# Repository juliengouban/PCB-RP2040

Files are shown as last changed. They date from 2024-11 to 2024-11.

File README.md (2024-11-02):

# PCB-RP2040

We've realized an electronic board based on the RP2040.
This microcontroller has 2 MB of flash memory, providing ample storage space for programs and data. It has 26 digital I/O pins, 3 of which can be used as analog inputs.
The RP20240 is used for the Raspberry Pico board and is programmable in micro-Python or directly with Arduino Ide.
We developed the board on Kicad and had it manufactured on jpclb. It costs around 17 euros per board, and is a 2-layer board measuring 2.7cm x 2 cm. You can find the files on our github.

<h1> Electronic diagram</h1>
We'll now take a closer look at how our electronic board works: 

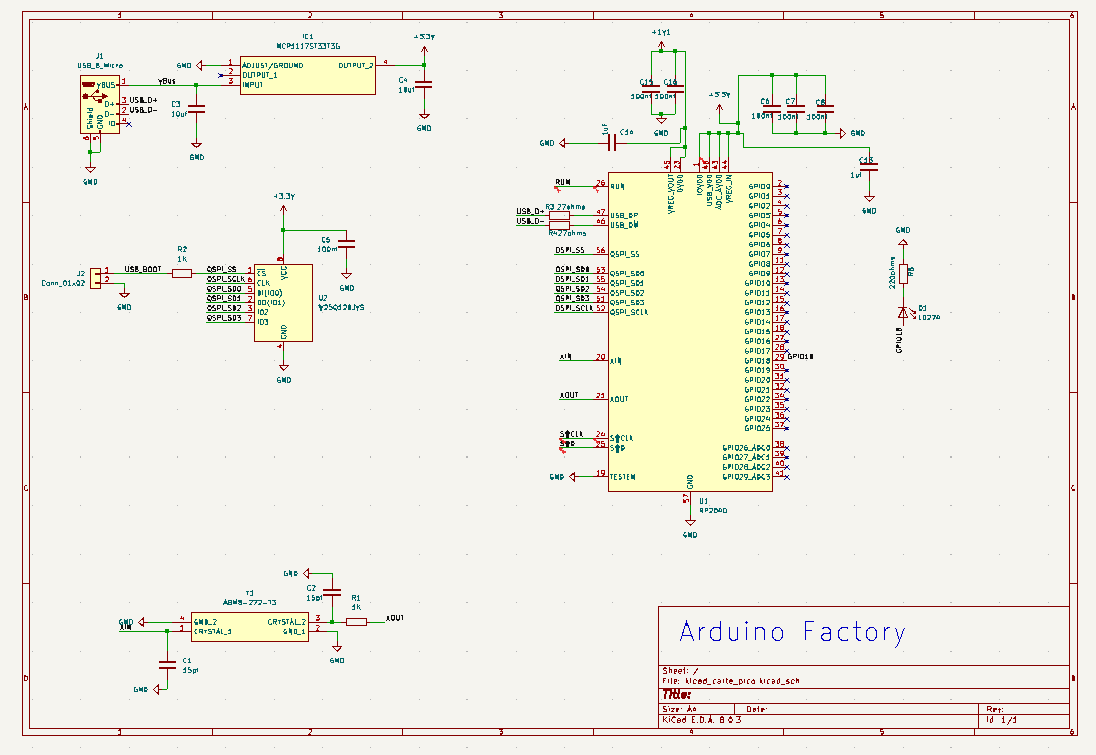
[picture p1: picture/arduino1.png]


For powering the circuit, we've used a Micro USB type B connector to supply our board with 5V. As the RP2040 uses 3.3V, we've fitted a regulator to convert 5V to +3.3V: 

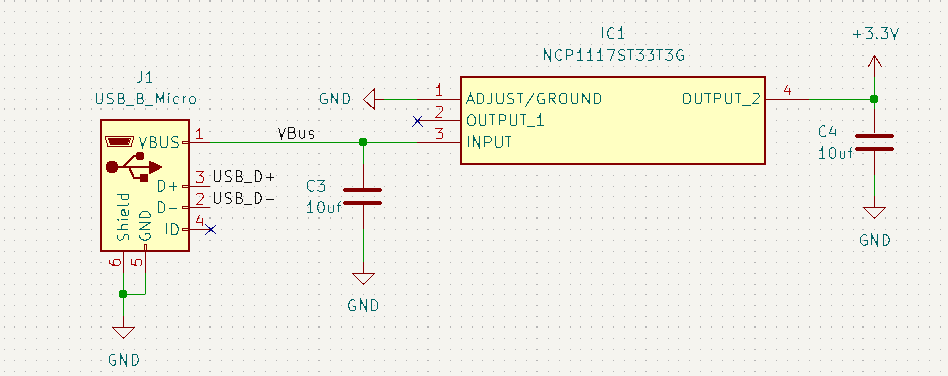
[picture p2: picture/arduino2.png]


This is where you'll find the 128-megabit flash memory to store the program. The 2-pin connector allows you to force USB boot:

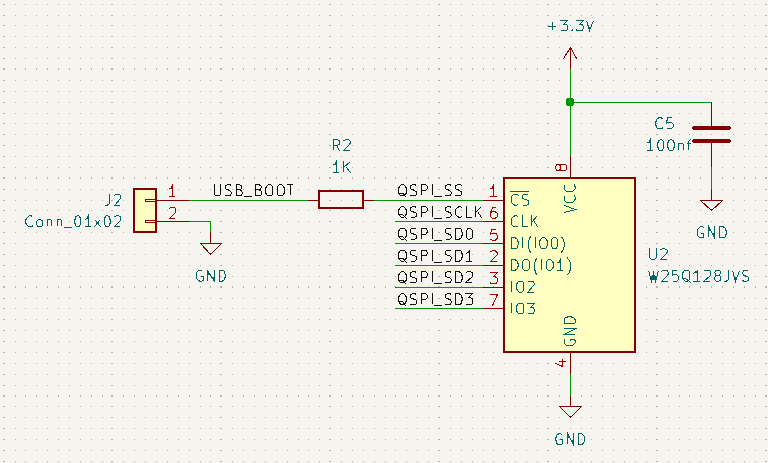
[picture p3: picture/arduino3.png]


The 12Mhz crystal provides the clock for our RP2040 microcontroller:

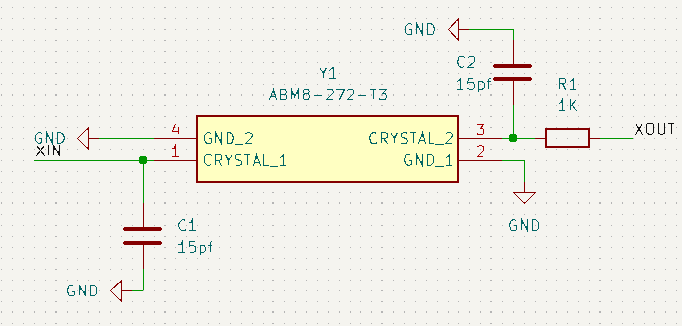
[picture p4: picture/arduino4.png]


We have added a LED to be programmed on GPIO18 to check that our card is working properly: 
PCB in 3D view

Finally, we have the RP2040 microncontroller. It is supplied with 3.3V with decoupling capacitors:
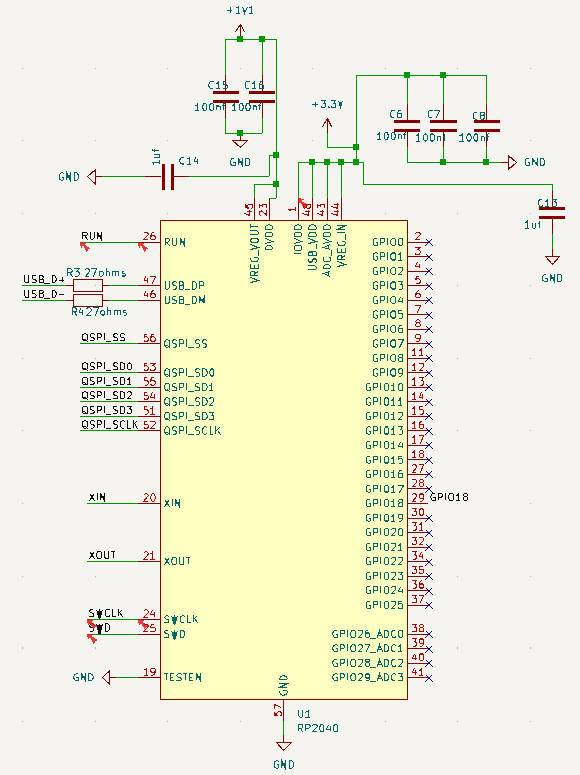
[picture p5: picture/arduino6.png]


<h1>PCB Design</h1>

The board is a 2-layer design. On the top you can see the 3.3V regulator and the Micro-USB type B connector.
In the middle of the board you'll find the flash memory and the RP2040 microcontroller.
At the bottom of the board you'll find the 2-pin USB boot connector and the 12Mhz quartz crystal.
A ground plane has been created on the TOP layer to connect all the GNDs together.

Here are the 3d and top layer views of the PCB:

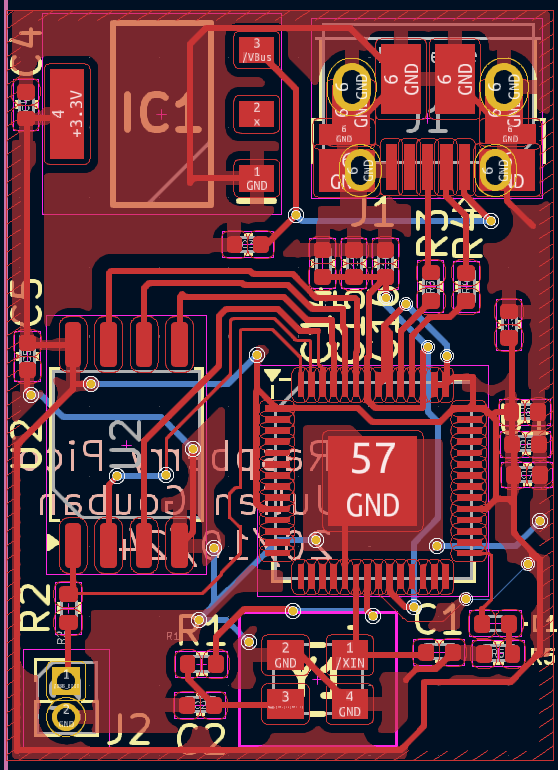
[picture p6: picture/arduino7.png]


Here is a 3d view of the PCB:

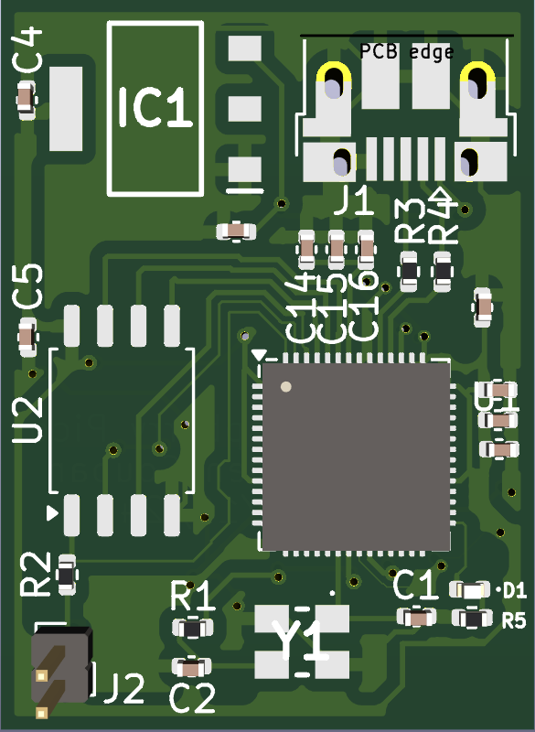
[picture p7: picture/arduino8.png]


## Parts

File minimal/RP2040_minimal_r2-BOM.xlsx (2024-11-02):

RP2040_minimal_r2 BOM
Item | Quantity | Reference | Part | Voltage | Current | Power | Material | Size | Tolerance | Manufacturer | Manuf. Part # | Description | Notes
1 | 3 | C1,C4,C17 | 10u | 16V |  |  | X5R | 0805_2012Metric | 10% | Murata | GRM21BR61C106KE15K | CAP CER 10UF 16V X5R 0805 | Or equivalent
2 | 2 | C2, C3 | 15p | 50V |  |  | C0G | 0402_1005Metric | 5% | Murata | GCM1555C1H150JA16D | CAP CER 15PF 50V C0G/NP0 0402 | Or equivalent
3 | 10 | C5, C6, C7, C9, C11, C12, C13, C14, C15, C16 | 100n | 25V |  |  | X7R | 0402_1005Metric | 10% | Murata | GRM155R71E104KE14J | CAP CER 0.1UF 25V X7R 0402 | Or equivalent
4 | 2 | C8, C10 | 1u | 10V |  |  | X6S | 0402_1005Metric | 10% | Murata | GRM155C81A105KA12D | CAP CER 1UF 10V X6S 0402 | Or equivalent
5 | 1 | J1 | USB_B_Micro |  |  |  |  |  |  | Amphenol | 10103594-0001LF | CONN RCPT USB2.0 MICRO B SMD R/A | Or equivalent
6 | 1 | J2 | 1x2 way header |  |  |  |  |  |  | Samtec | TSW-102-23-T-S | 2.54mm pin header 1x2 | Or equivalent
7 | 2 | J3, J4 | 2x18 way header |  |  |  |  |  |  | Samtec | TSW-118-23-T-D | 2.54mm pin header 2x18 | Or equivalent
8 | 2 | R1, R5 | 1k |  |  | 63mW |  | 0402_1005Metric | 1% | Yageo | RC0402FR-071KP | RES SMD 1K OHM 1% 1/16W 0402 | Or equivalent
9 | 1 | R2 | DNF |  |  |  |  | 0402_1005Metric |  |  |  |  | Do Not Fit
10 | 2 | R3, R4 | 27.4 |  |  | 63mW |  | 0402_1005Metric | 1% | Yageo | RC0402FR-0727R4L | RES SMD 27.4 OHM 1% 1/16W 0402 | Or equivalent
11 | 1 | U1 | NCP1117-3.3 |  |  |  |  | SOT-223-3 |  | ON Semiconductor | NCP1117ST33T3G | IC REG LINEAR 3.3V 1A SOT223
12 | 1 | U2 | W25Q128JVS |  |  |  |  | SOIC-8 |  | Winbond | W25Q128JVSIQ TR | IC FLASH 128M SPI 133MHZ 8SOIC
13 | 1 | U3 | RP2040 |  |  |  |  | QFN56 |  | Raspberry Pi | RP2040
14 | 1 | Y1 | ABM8-272-T3 |  |  |  |  | SMD_3225 |  | Abracon | ABM8-272-T3 | CRYSTAL 12.0000MHZ 3.2x2.5MM SMD

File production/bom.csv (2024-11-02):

Designator | Footprint | Quantity | Value | LCSC Part #
C1, C2 | 0402 | 2 | 15pf
C13, C14 | 0402 | 2 | 1uf
C15, C16, C5, C6, C7, C8 | 0402 | 6 | 100nf
C3, C4 | 0402 | 2 | 10uf
D1 | 0402 | 1 | LD274
IC1 | SOT230P700X180-4N | 1 | NCP1117ST33T3G
J1 | USB_Micro-B_Amphenol_10103594-0001LF_Horizontal | 1 | USB_B_Micro
J2 | PinHeader_1x02_P1.27mm_Vertical | 1 | Conn_01x02
R1, R2 | 0402 | 2 | 1K
R3, R4 | 0402 | 2 | 27ohms
R5 | 0402 | 1 | 220ohms
U1 | QFN-56-1EP_7x7mm_P0.4mm_EP3.2x3.2mm | 1 | RP2040
U2 | SOIC-8_5.23x5.23mm_P1.27mm | 1 | W25Q128JVS
Y1 | ABM8272T3 | 1 | ABM8-272-T3

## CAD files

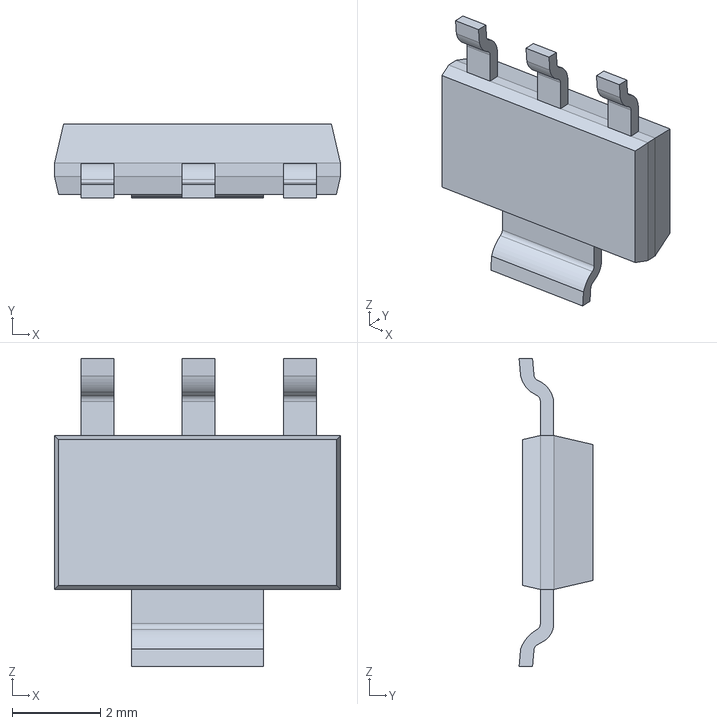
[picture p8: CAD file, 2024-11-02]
NCP1117/ncp1117st50t3g.stp
6.50 x 1.68 x 7.00 mm

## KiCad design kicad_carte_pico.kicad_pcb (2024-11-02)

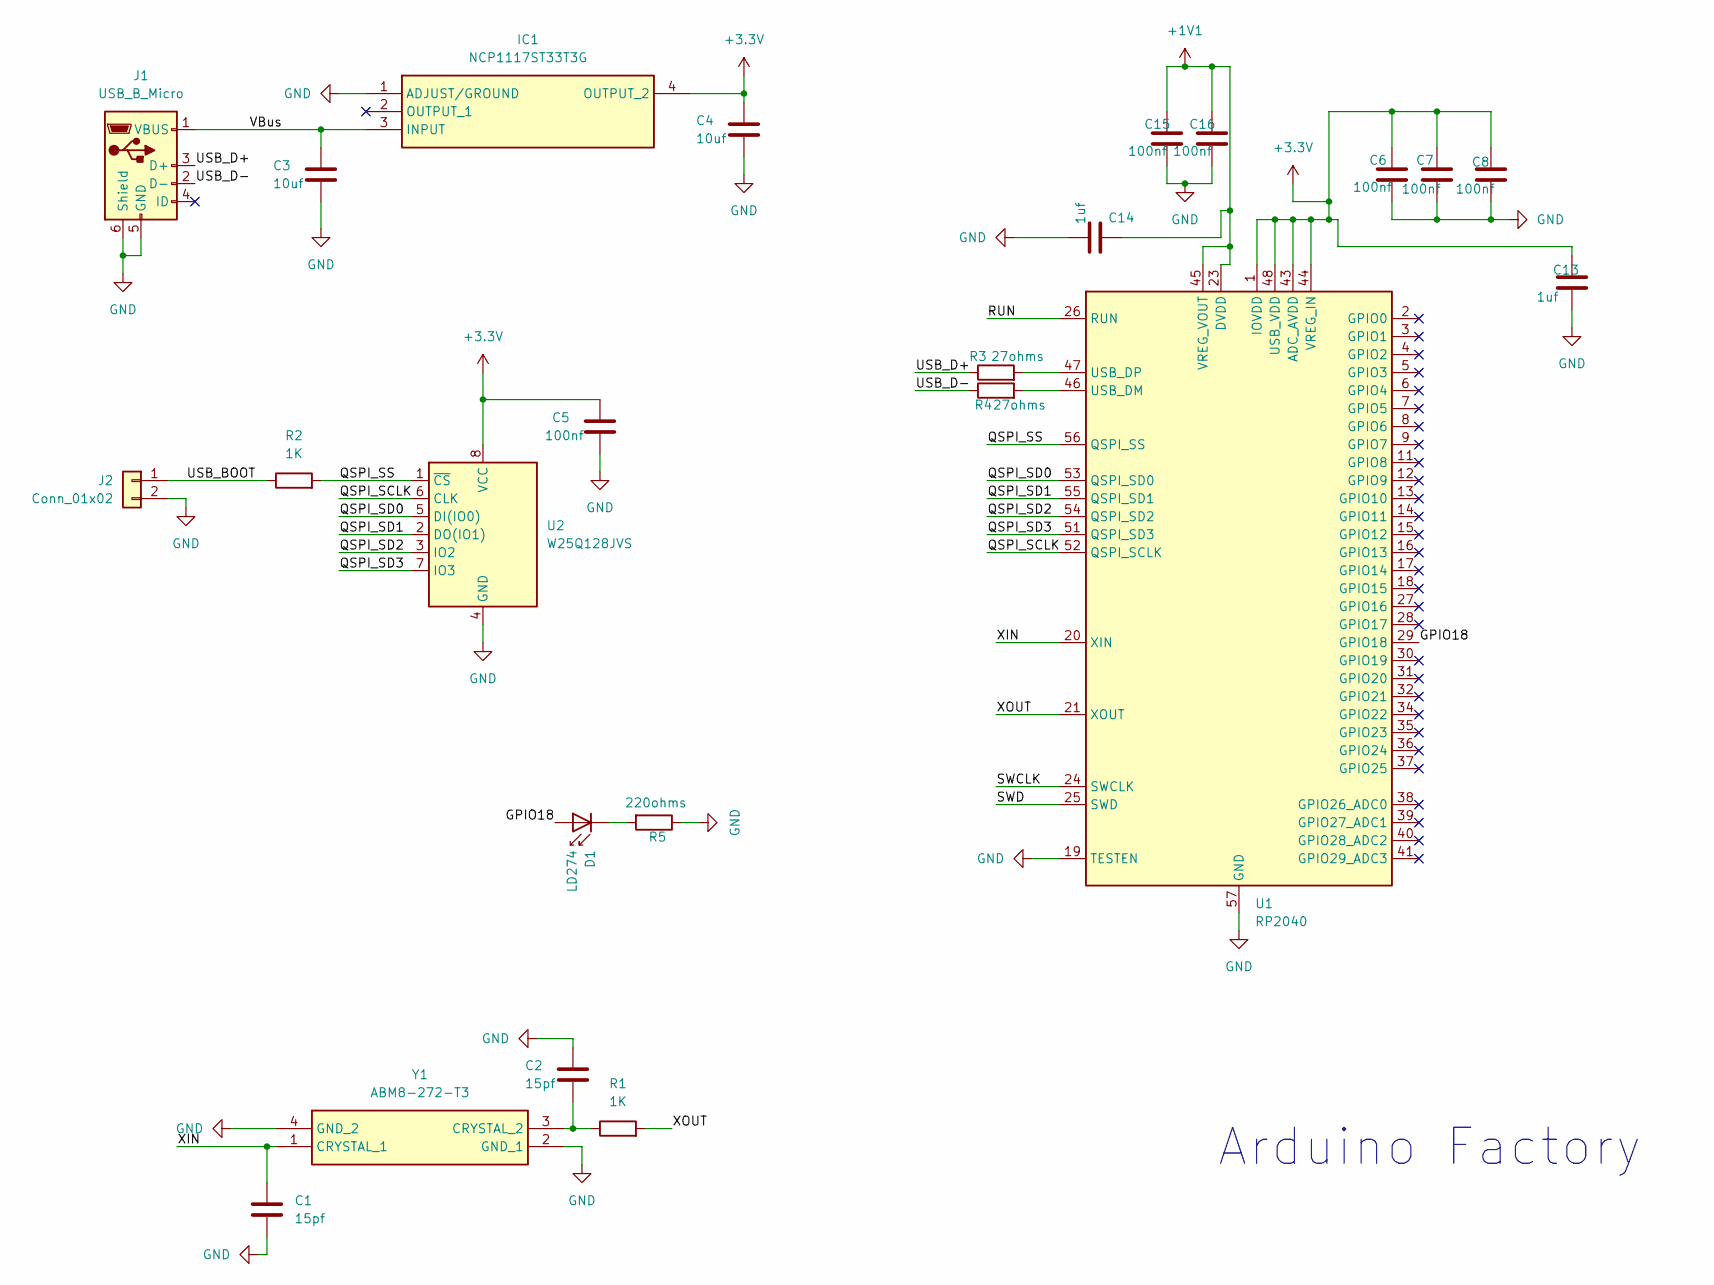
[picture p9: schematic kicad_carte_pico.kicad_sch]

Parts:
C1, C2: 15pf; C_0402_1005Metric
C3, C4: 10uf; C_0402_1005Metric
C5, C6, C7, C8, C15, C16: 100nf; C_0402_1005Metric
C13, C14: 1uf; C_0402_1005Metric
D1: LD274; LED_0402_1005Metric
IC1: NCP1117ST33T3G; SOT230P700X180-4N; Manufacturer_Part_Number NCP1117ST33T3G; Mouser Part Number 863-NCP1117ST33T3G
J1: USB_B_Micro; USB_Micro-B_Amphenol_10103594-0001LF_Horizontal
J2: Conn_01x02; PinHeader_1x02_P1.27mm_Vertical
R1, R2: 1K; R_0402_1005Metric
R3, R4: 27ohms; R_0402_1005Metric
R5: 220ohms; R_0402_1005Metric
U1: RP2040; QFN-56-1EP_7x7mm_P0.4mm_EP3.2x3.2mm
U2: W25Q128JVS; SOIC-8_5.23x5.23mm_P1.27mm
Y1: ABM8-272-T3; ABM8272T3; Mouser Part Number 815-ABM8-272-T3

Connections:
+1V1: C14.1, C15.1, C16.1, U1.23 (DVDD), U1.45 (VREG_VOUT), U1.50 (DVDD)
+3.3V: C4.1, C5.1, C6.1, C7.1, C8.1, C13.1, IC1.4 (OUTPUT_2), U1.1 (IOVDD), U1.10 (IOVDD), U1.22 (IOVDD), U1.33 (IOVDD), U1.42 (IOVDD), U1.43 (ADC_AVDD), U1.44 (VREG_IN), U1.48 (USB_VDD), U1.49 (IOVDD), U2.8 (VCC)
/GPIO18: D1.2 (A), U1.29 (GPIO18)
/QSPI_SCLK: U1.52 (QSPI_SCLK), U2.6 (CLK)
/QSPI_SD0: U1.53 (QSPI_SD0), U2.5 (DI(IO0))
/QSPI_SD1: U1.55 (QSPI_SD1), U2.2 (DO(IO1))
/QSPI_SD2: U1.54 (QSPI_SD2), U2.3 (IO2)
/QSPI_SD3: U1.51 (QSPI_SD3), U2.7 (IO3)
/QSPI_SS: R2.2, U1.56 (QSPI_SS), U2.1 (~CS)
/RUN: U1.26 (RUN)
/SWCLK: U1.24 (SWCLK)
/SWD: U1.25 (SWD)
/USB_BOOT: J2.1, R2.1
/USB_D+: J1.3 (D+), R3.1
/USB_D-: J1.2 (D-), R4.1
/VBus: C3.1, IC1.3 (INPUT), J1.1 (VBUS)
/XIN: C1.1, U1.20 (XIN), Y1.1 (CRYSTAL_1)
/XOUT: R1.2, U1.21 (XOUT)
GND: C1.2, C2.1, C3.2, C4.2, C5.2, C6.2, C7.2, C8.2, C13.2, C14.2, C15.2, C16.2, IC1.1 (ADJUST/GROUND), J1.5 (GND), J1.6 (Shield), J2.2, R5.1, U1.19 (TESTEN), U1.57 (GND), U2.4 (GND), Y1.2 (GND_1), Y1.4 (GND_2)
unnamed: D1.1 (K), R5.2
unnamed: R4.2, U1.46 (USB_DM)
unnamed: R3.2, U1.47 (USB_DP)
unnamed: C2.2, R1.1, Y1.3 (CRYSTAL_2)

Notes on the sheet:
Arduino Factory

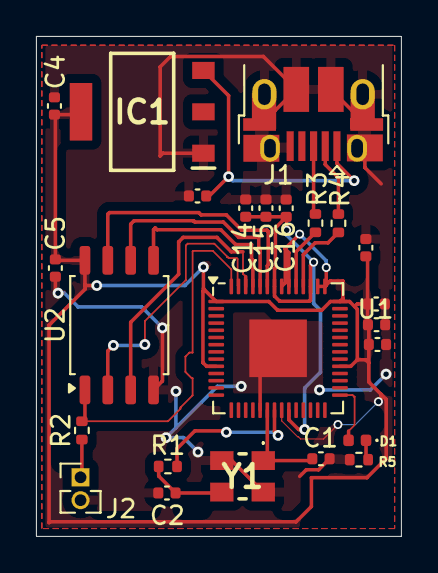
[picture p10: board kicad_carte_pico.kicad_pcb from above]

Board: 2 copper layers, 20.3 x 27.8 mm, 24 parts (0 on the bottom side), 20 nets.

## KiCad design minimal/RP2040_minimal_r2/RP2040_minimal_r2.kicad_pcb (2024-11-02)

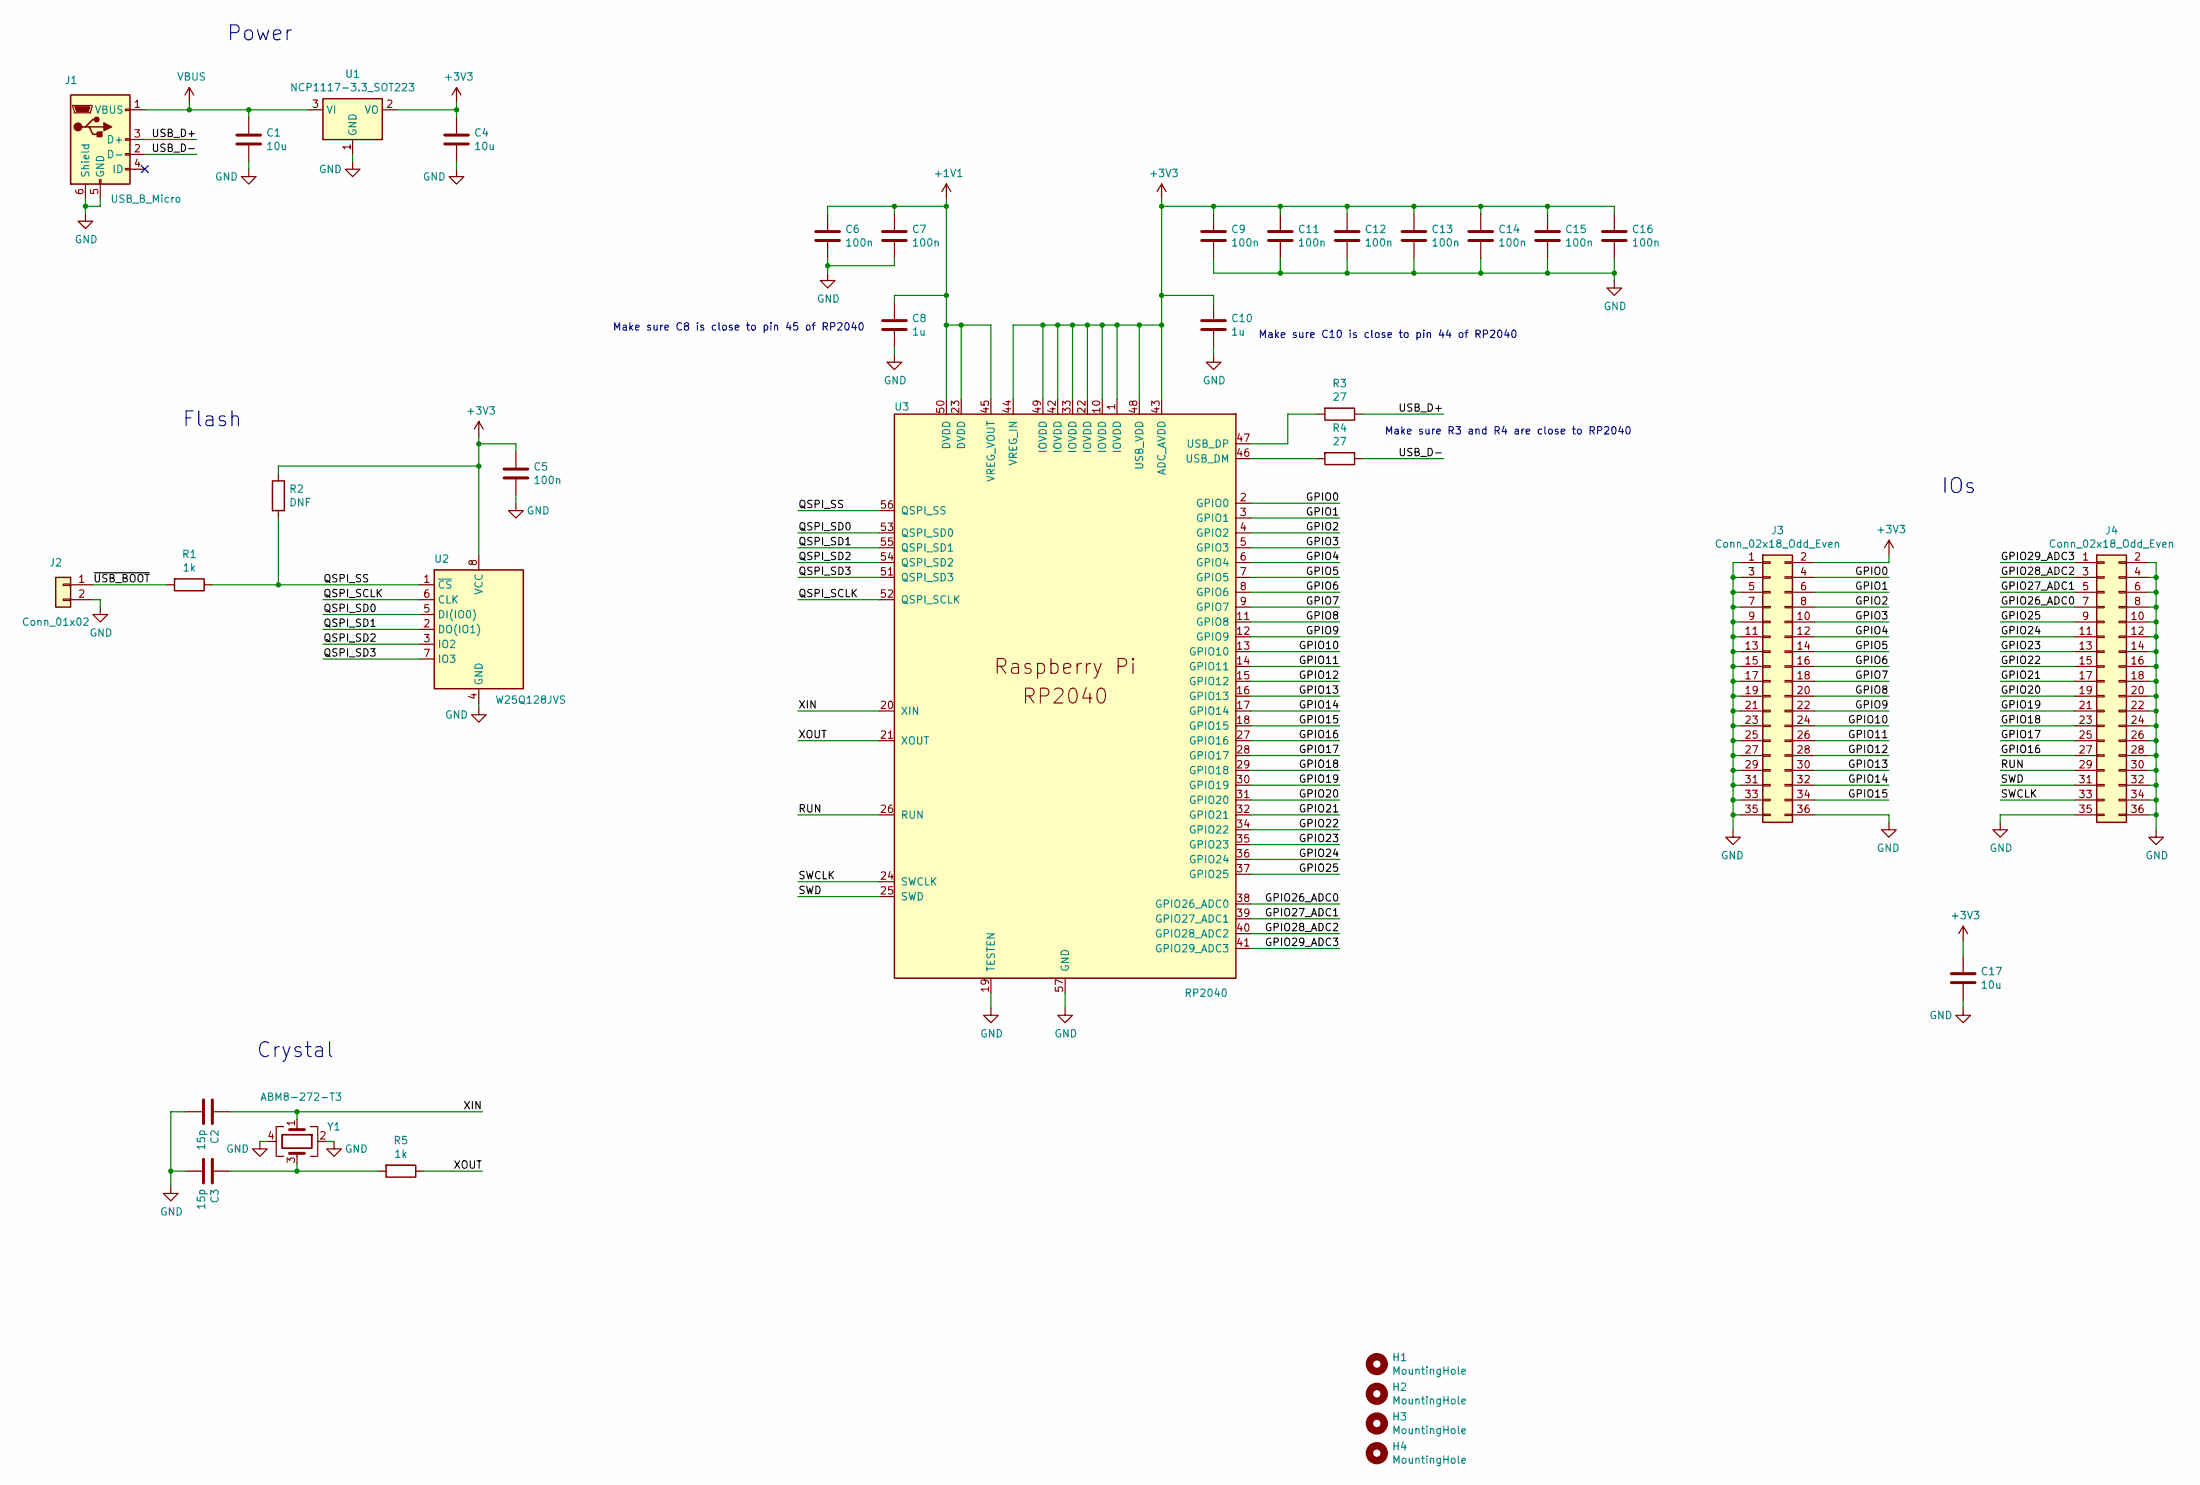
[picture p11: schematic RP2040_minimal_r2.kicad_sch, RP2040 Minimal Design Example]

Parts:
C1, C4, C17: 10u; C_0805_2012Metric
C2, C3: 15p; C_0402_1005Metric
C5, C6, C7, C9, C11, C12, C13, C14, C15, C16: 100n; C_0402_1005Metric
C8, C10: 1u; C_0402_1005Metric
H1, H2, H3, H4: MountingHole; MountingHole_2.7mm_M2.5
J1: USB_B_Micro; USB_Micro-B_Amphenol_10103594-0001LF_Horizontal_modified
J2: Conn_01x02; PinHeader_1x02_P2.54mm_Vertical
J3, J4: Conn_02x18_Odd_Even; PinHeader_2x18_P2.54mm_Vertical
R1, R5: 1k; R_0402_1005Metric
R2: DNF; R_0402_1005Metric
R3, R4: 27; R_0402_1005Metric
U1: NCP1117-3.3_SOT223; SOT-223-3_TabPin2
U2: W25Q128JVS; SOIC-8_5.23x5.23mm_P1.27mm
U3: RP2040; RP2040-QFN-56
Y1: ABM8-272-T3; Crystal_SMD_3225-4Pin_3.2x2.5mm

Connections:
+1V1: C6.1, C7.1, C8.1, U3.23 (DVDD), U3.45 (VREG_VOUT), U3.50 (DVDD)
+3V3: C4.1, C5.1, C9.1, C10.1, C11.1, C12.1, C13.1, C14.1, C15.1, C16.1, C17.1, J3.2, R2.1, U1.2 (VO), U2.8 (VCC), U3.1 (IOVDD), U3.10 (IOVDD), U3.22 (IOVDD), U3.33 (IOVDD), U3.42 (IOVDD), U3.43 (ADC_AVDD), U3.44 (VREG_IN), U3.48 (USB_VDD), U3.49 (IOVDD)
/GPIO0: J3.4, U3.2 (GPIO0)
/GPIO1: J3.6, U3.3 (GPIO1)
/GPIO2: J3.8, U3.4 (GPIO2)
/GPIO3: J3.10, U3.5 (GPIO3)
/GPIO4: J3.12, U3.6 (GPIO4)
/GPIO5: J3.14, U3.7 (GPIO5)
/GPIO6: J3.16, U3.8 (GPIO6)
/GPIO7: J3.18, U3.9 (GPIO7)
/GPIO8: J3.20, U3.11 (GPIO8)
/GPIO9: J3.22, U3.12 (GPIO9)
/GPIO10: J3.24, U3.13 (GPIO10)
/GPIO11: J3.26, U3.14 (GPIO11)
/GPIO12: J3.28, U3.15 (GPIO12)
/GPIO13: J3.30, U3.16 (GPIO13)
/GPIO14: J3.32, U3.17 (GPIO14)
/GPIO15: J3.34, U3.18 (GPIO15)
/GPIO16: J4.27, U3.27 (GPIO16)
/GPIO17: J4.25, U3.28 (GPIO17)
/GPIO18: J4.23, U3.29 (GPIO18)
/GPIO19: J4.21, U3.30 (GPIO19)
/GPIO20: J4.19, U3.31 (GPIO20)
/GPIO21: J4.17, U3.32 (GPIO21)
/GPIO22: J4.15, U3.34 (GPIO22)
/GPIO23: J4.13, U3.35 (GPIO23)
/GPIO24: J4.11, U3.36 (GPIO24)
/GPIO25: J4.9, U3.37 (GPIO25)
/GPIO26_ADC0: J4.7, U3.38 (GPIO26_ADC0)
/GPIO27_ADC1: J4.5, U3.39 (GPIO27_ADC1)
/GPIO28_ADC2: J4.3, U3.40 (GPIO28_ADC2)
/GPIO29_ADC3: J4.1, U3.41 (GPIO29_ADC3)
/QSPI_SCLK: U2.6 (CLK), U3.52 (QSPI_SCLK)
/QSPI_SD0: U2.5 (DI(IO0)), U3.53 (QSPI_SD0)
/QSPI_SD1: U2.2 (DO(IO1)), U3.55 (QSPI_SD1)
/QSPI_SD2: U2.3 (IO2), U3.54 (QSPI_SD2)
/QSPI_SD3: U2.7 (IO3), U3.51 (QSPI_SD3)
/QSPI_SS: R1.1, R2.2, U2.1 (~CS), U3.56 (QSPI_SS)
/RUN: J4.29, U3.26 (RUN)
/SWCLK: J4.33, U3.24 (SWCLK)
/SWD: J4.31, U3.25 (SWD)
/USB_D+: J1.3 (D+), R3.1
/USB_D-: J1.2 (D-), R4.1
/XIN: C2.1, U3.20 (XIN), Y1.1
/XOUT: R5.1, U3.21 (XOUT)
/~USB_BOOT: J2.1, R1.2
GND: C1.2, C2.2, C3.2, C4.2, C5.2, C6.2, C7.2, C8.2, C9.2, C10.2, C11.2, C12.2, C13.2, C14.2, C15.2, C16.2, C17.2, J1.5 (GND), J1.6 (Shield), J2.2, J3.1, J3.3, J3.5, J3.7, J3.9, J3.11, J3.13, J3.15, J3.17, J3.19, J3.21, J3.23, J3.25, J3.27, J3.29, J3.31, J3.33, J3.35, J3.36, J4.2, J4.4, J4.6, J4.8, J4.10, J4.12, J4.14, J4.16, J4.18, J4.20, J4.22, J4.24, J4.26, J4.28, J4.30, J4.32, J4.34, J4.35, J4.36, U1.1 (GND), U2.4 (GND), U3.19 (TESTEN), U3.57 (GND), Y1.2, Y1.4
unnamed: C3.1, R5.2, Y1.3
unnamed: R4.2, U3.46 (USB_DM)
unnamed: R3.2, U3.47 (USB_DP)
VBUS: C1.1, J1.1 (VBUS), U1.3 (VI)

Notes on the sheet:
IOs
Power
Crystal
Make sure C8 is close to pin 45 of RP2040
Make sure C10 is close to pin 44 of RP2040
Make sure R3 and R4 are close to RP2040
Flash


Board: 2 copper layers, 52.0 x 51.0 mm, 34 parts (0 on the bottom side), 51 nets.
